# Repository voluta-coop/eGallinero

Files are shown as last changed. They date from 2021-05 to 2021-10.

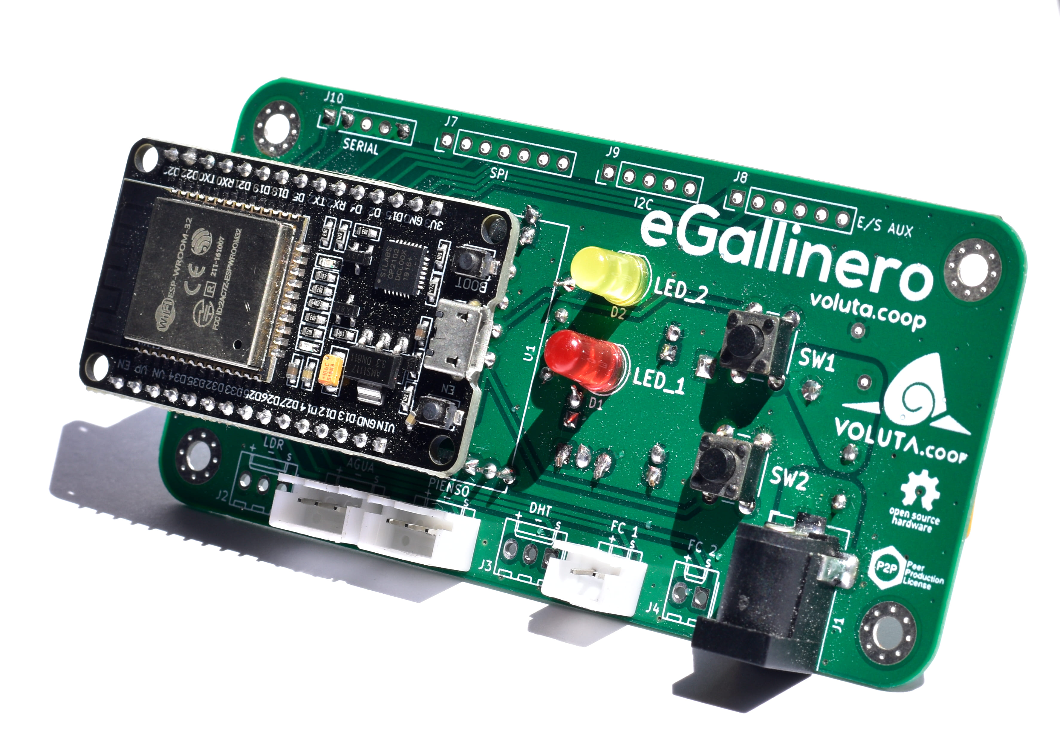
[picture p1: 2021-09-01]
Images/_DSC0914.jpg

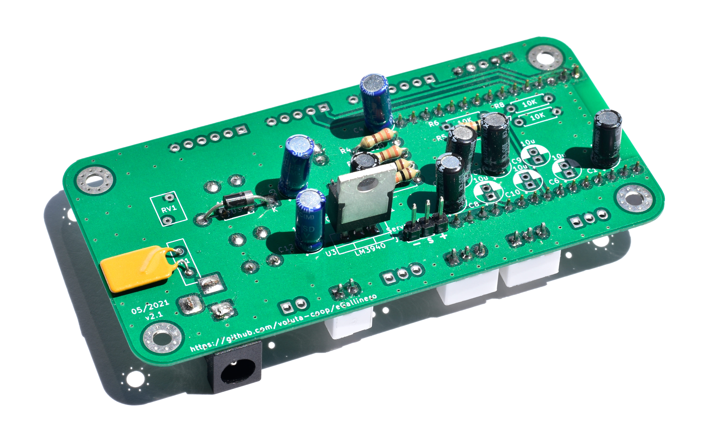
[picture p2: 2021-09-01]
Images/_DSC0912.jpg

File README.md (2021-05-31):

# eGallinero
El eGallinero es un sistema modular, diseñado para facilitar las tareas que conllevan los cuidados a los animales. En nuestro caso lo hemos enfocado comercialmente a las gallinas para alinearlo con nuestro objeto social, conectar mundo rural y urbano... pero se puede utilizar para multitud de aplicaciones que requieran automatización y monitorización.

¡Reserva el tuyo!

[**RESERVA**](https://www.voluta.coop/taller-iot-competencias-digitales/)  

[**Canal de Telegram**](https://t.me/eGallinero)

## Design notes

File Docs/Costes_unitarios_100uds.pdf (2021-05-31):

Concepto | €
Componentes + embalaje + transporte | 24,82 €
Mano de obra + gestión del pedido + postventa | 24,49 €
Beneficio empresarial | 7,72 €
IVA (21%) | 11,98 €
TOTAL | 69,00 €

A continuación desglosamos el precio de cada Kit eGallinero asumiendo una fabricación en lotes de 100 unidades:

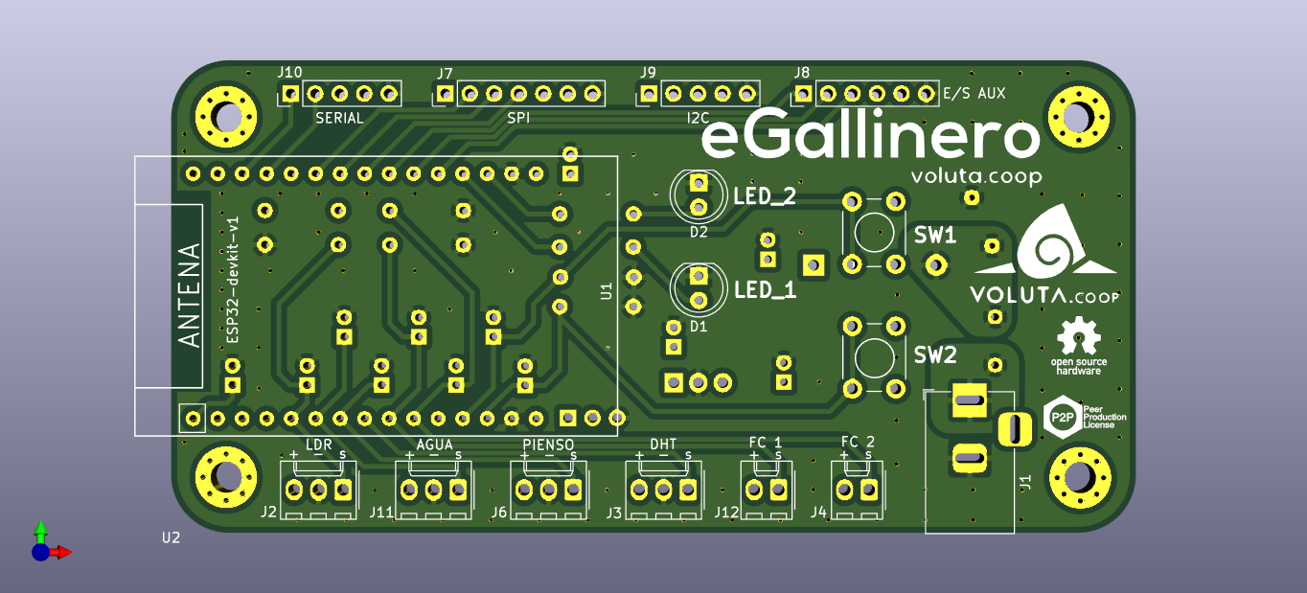
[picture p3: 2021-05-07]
Images/eGallinero_TOP.png

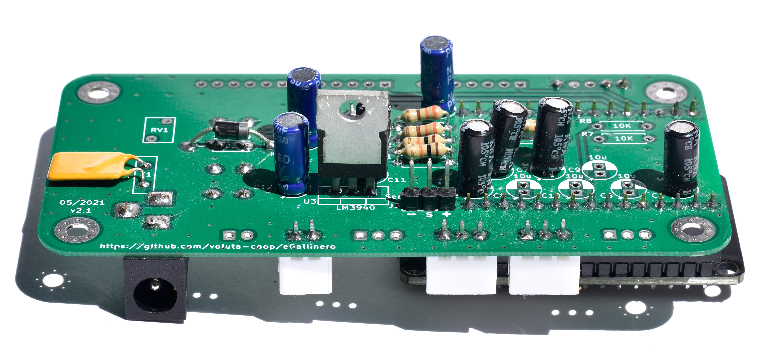
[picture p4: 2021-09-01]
Images/_DSC0917.jpg

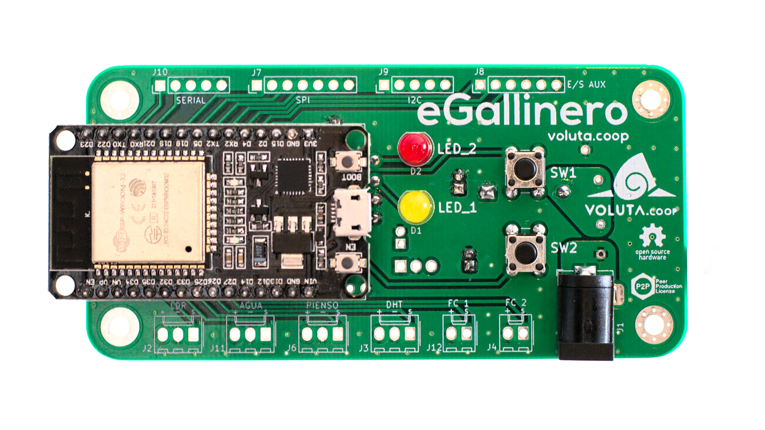
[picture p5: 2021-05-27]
Images/eGallinero.jpg

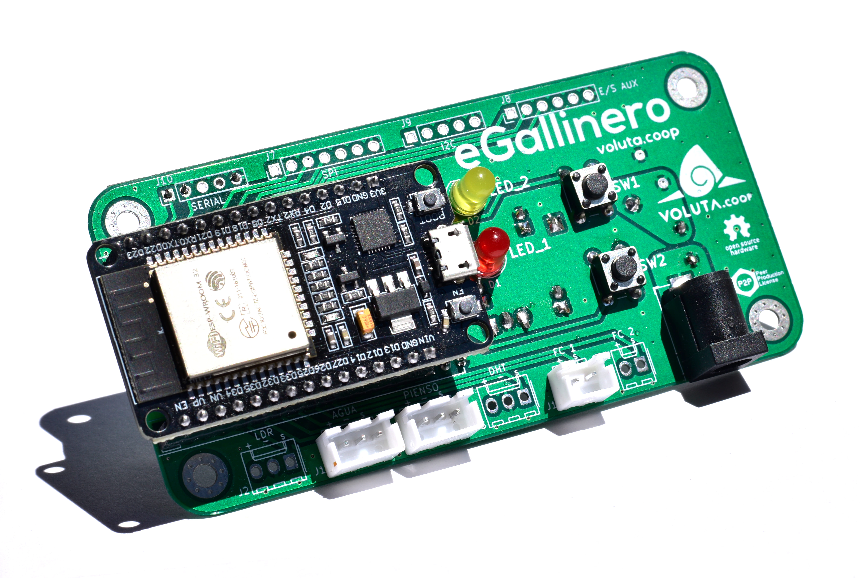
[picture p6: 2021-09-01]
Images/_DSC0913.jpg

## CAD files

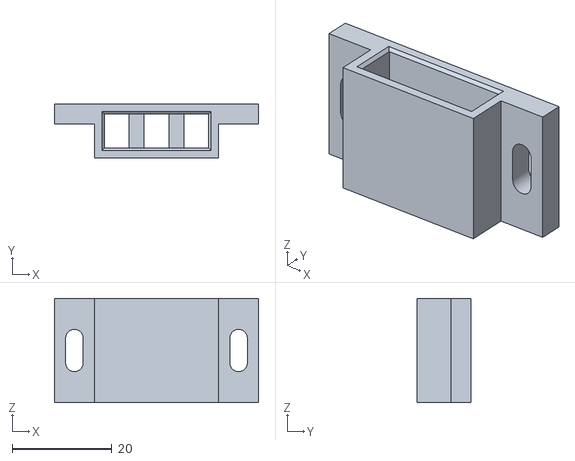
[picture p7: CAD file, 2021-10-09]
HW/3D/soporte_final_de_carrera.stl
41.0 x 10.8 x 21.0

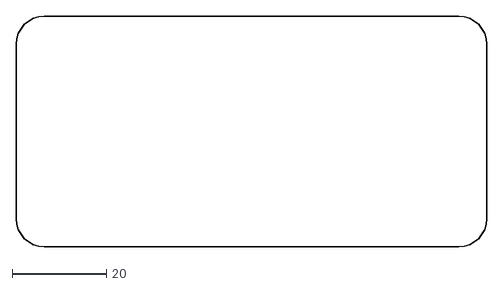
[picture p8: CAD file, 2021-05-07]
HW/kicad/eGallinero/edge.dxf
100.0 x 49.0

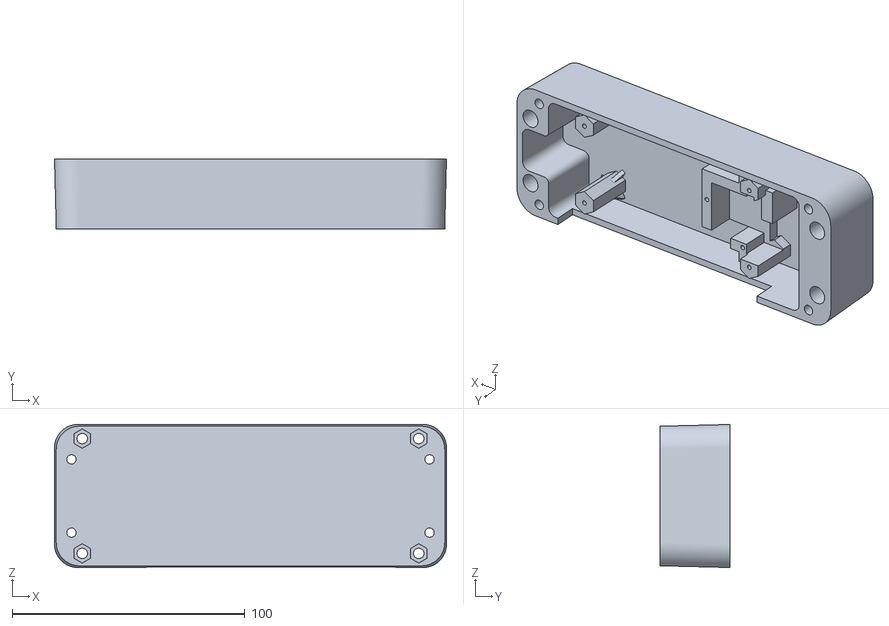
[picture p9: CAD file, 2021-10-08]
HW/3D/caja.stl
168.5 x 30.0 x 61.5

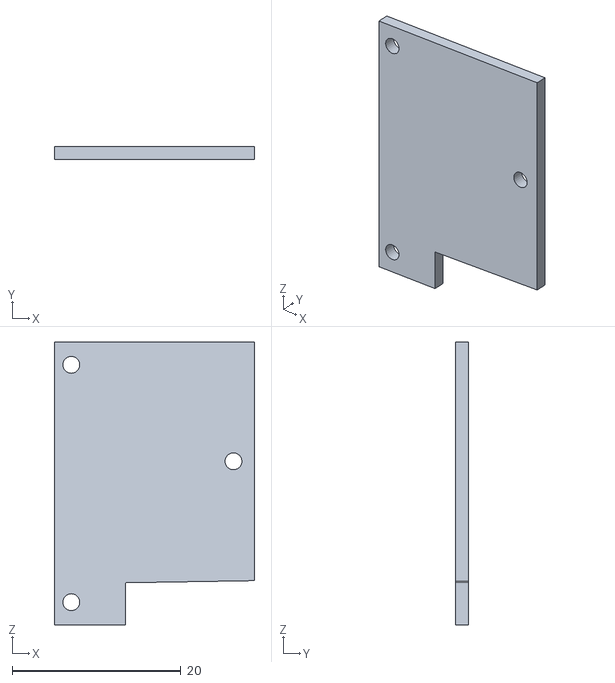
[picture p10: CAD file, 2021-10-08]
HW/3D/tapa_ servo.stl
23.7 x 1.50 x 33.5

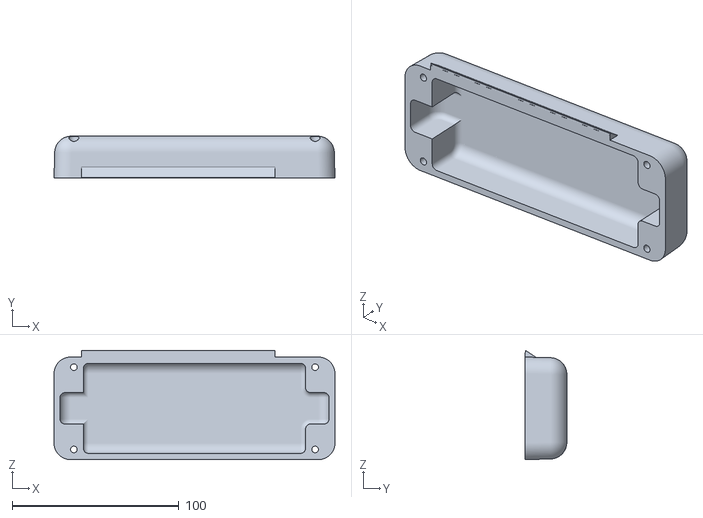
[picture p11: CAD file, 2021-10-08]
HW/3D/tapa_ caja.stl
168.5 x 25.0 x 65.5

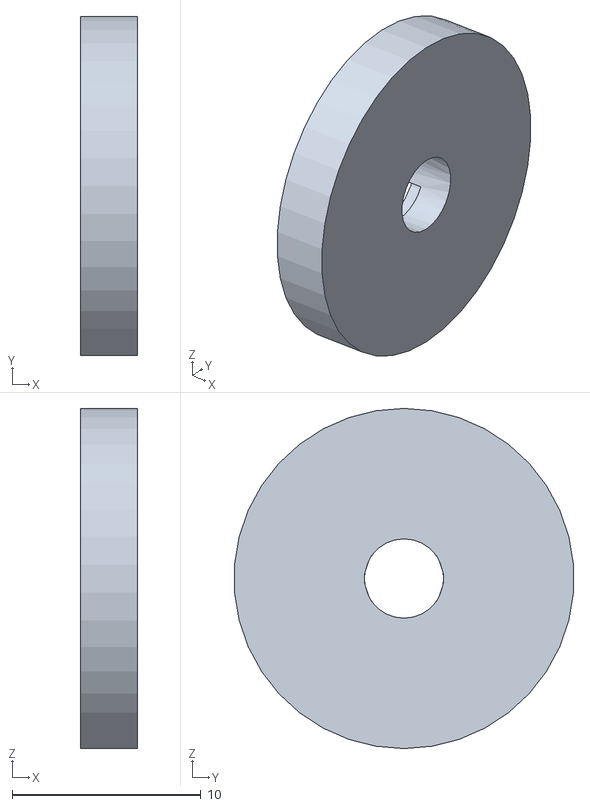
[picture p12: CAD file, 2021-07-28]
HW/3D/Bobina_1.stl
3.00 x 17.9 x 18.0

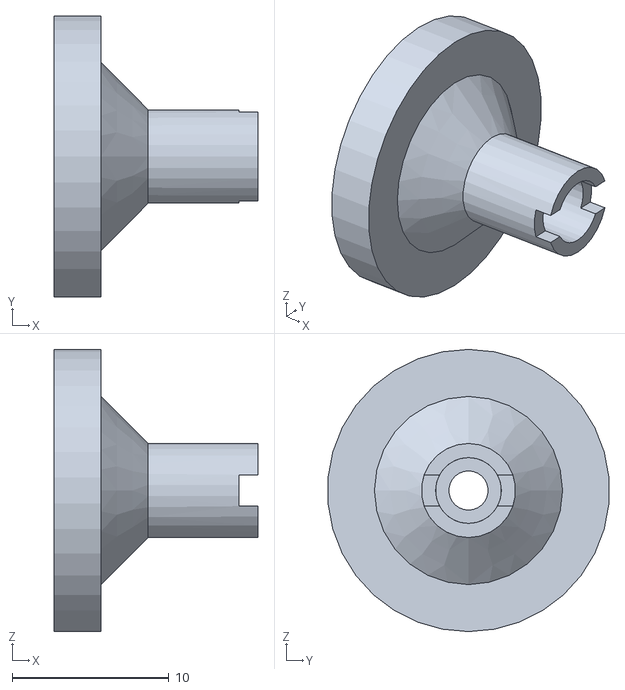
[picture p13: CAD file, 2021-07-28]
HW/3D/Bobina_2.stl
13.0 x 17.9 x 18.0

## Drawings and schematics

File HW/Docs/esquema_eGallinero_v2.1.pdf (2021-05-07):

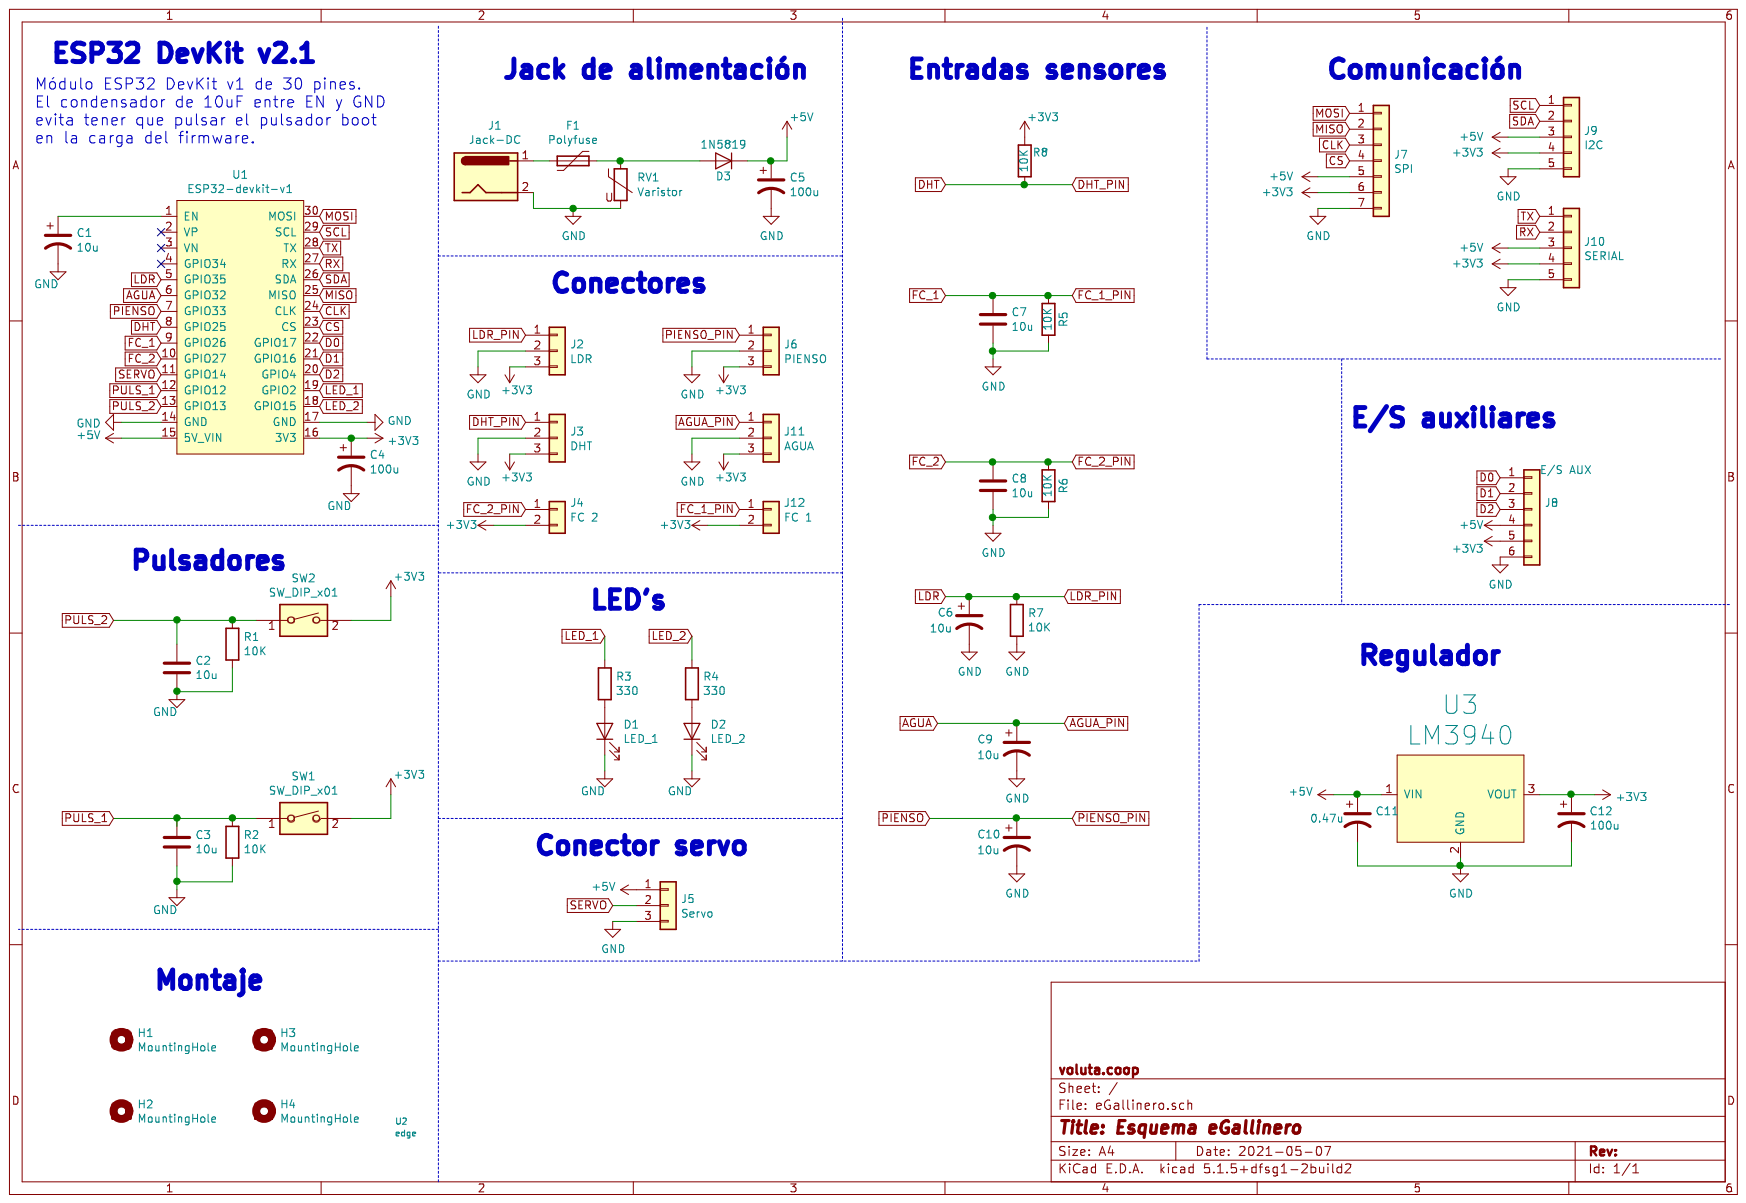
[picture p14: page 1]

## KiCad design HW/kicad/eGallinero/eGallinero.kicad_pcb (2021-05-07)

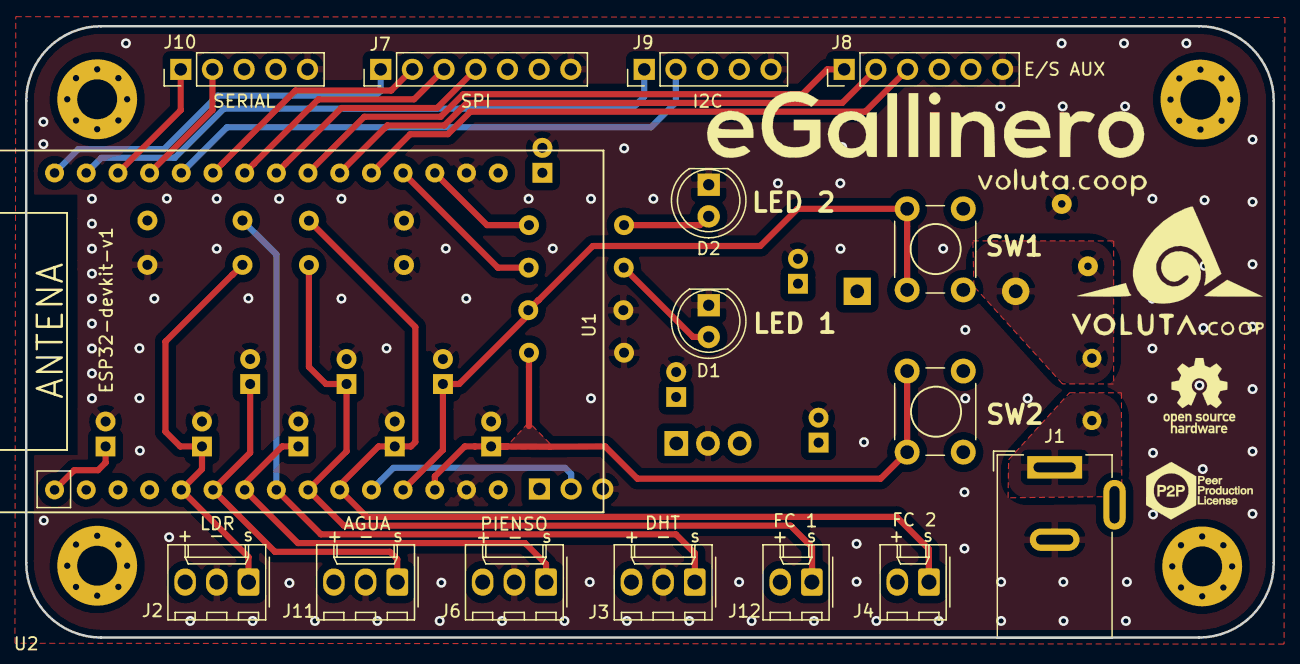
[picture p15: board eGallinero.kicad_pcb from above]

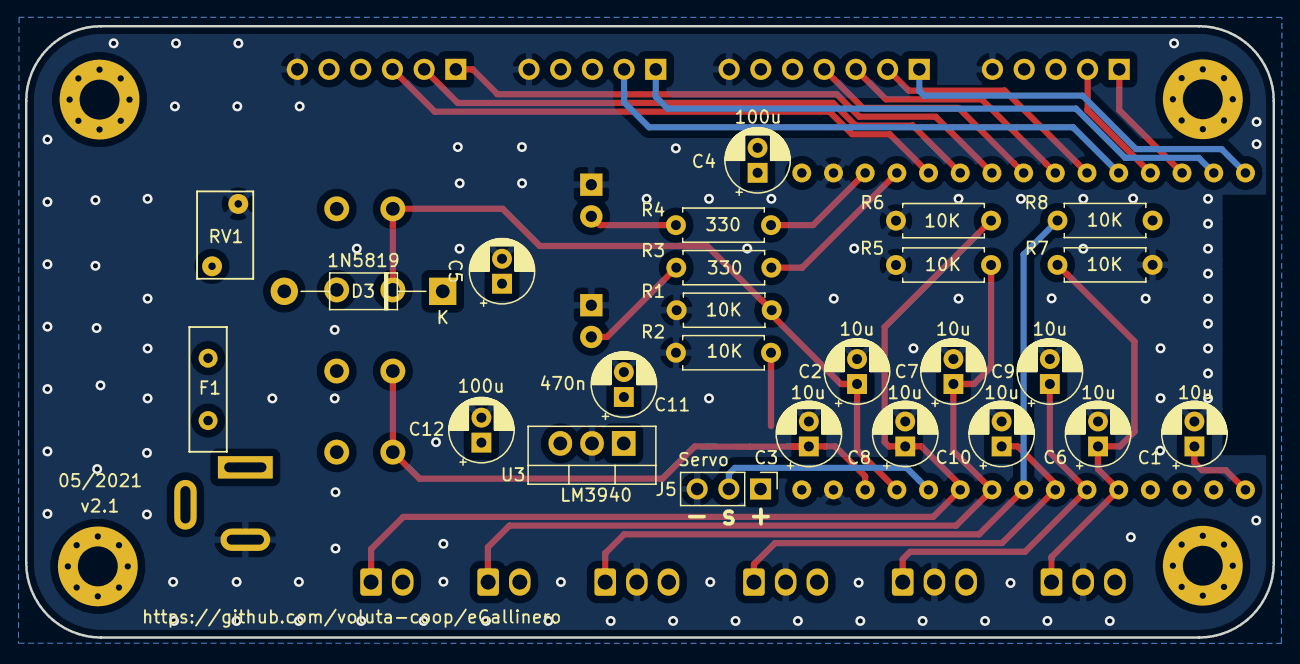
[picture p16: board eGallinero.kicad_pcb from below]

Board: 4 copper layers, 100.0 x 49.0 mm, 46 parts (25 on the bottom side), 30 nets.

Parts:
C1, C2, C3, C6, C7, C8, C9, C10: 10u; CP_Radial_D5.0mm_P2.00mm
C4, C5, C12: 100u; CP_Radial_D5.0mm_P2.00mm
C11: 470n; CP_Radial_D5.0mm_P2.00mm
D1: LED 1; LED_D5.0mm_Clear
D2: LED 2; LED_D5.0mm_Clear
D3: 1N5819; D_DO-41_SOD81_P12.70mm_Horizontal
F1: Polyfuse; AHEF100
H1, H2, H3, H4: MountingHole; MountingHole_3.2mm_M3_Pad_Via
J1: Jack-DC; BarrelJack_Wuerth_6941xx301002
J2: LDR; Molex_KK-254_AE-6410-03A_1x03_P2.54mm_Vertical
J3: DHT; Molex_KK-254_AE-6410-03A_1x03_P2.54mm_Vertical
J4: FC 2; Molex_KK-254_AE-6410-02A_1x02_P2.54mm_Vertical
J5: Servo; PinHeader_1x03_P2.54mm_Vertical
J6: PIENSO; Molex_KK-254_AE-6410-03A_1x03_P2.54mm_Vertical
J7: SPI; PinHeader_1x07_P2.54mm_Vertical
J8: E/S AUX; PinHeader_1x06_P2.54mm_Vertical
J9: I2C; PinHeader_1x05_P2.54mm_Vertical
J10: SERIAL; PinHeader_1x05_P2.54mm_Vertical
J11: AGUA; Molex_KK-254_AE-6410-03A_1x03_P2.54mm_Vertical
J12: FC 1; Molex_KK-254_AE-6410-02A_1x02_P2.54mm_Vertical
R1, R2, R5, R6, R7, R8: 10K; R_Axial_DIN0207_L6.3mm_D2.5mm_P7.62mm_Horizontal
R3, R4: 330; R_Axial_DIN0207_L6.3mm_D2.5mm_P7.62mm_Horizontal
RV1: Varistor; RV_Disc_D7mm_W4.5mm_P5mm
SW1, SW2: SW_DIP_x01; SW_PUSH_6mm_H4.3mm
U1: ESP32-devkit-v1; ESP32-DevKit-v1
U2: edge
U3: LM3940; TO-220-3_Vertical

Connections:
+3V3: C4.1, C12.1, J2.3, J3.3, J4.2, J6.3, J7.6, J8.5, J9.4, J10.4, J11.3, J12.2, R8.2, SW1.2, SW2.2, U1.16, U3.3
+5V: C5.1, C11.1, D3.1, J5.1, J7.5, J8.4, J9.3, J10.3, U1.15, U3.1
AGUA: C9.1, J11.1, U1.6
CLK: J7.3, U1.24
CS: J7.4, U1.23
D0: J8.1, U1.22
D1: J8.2, U1.21
D2: J8.3, U1.20
DHT: J3.1, R8.1, U1.8
FC_1: C7.1, J12.1, R5.2, U1.9
FC_2: C8.1, J4.1, R6.2, U1.10
GND: C1.2, C2.2, C3.2, C4.2, C5.2, C6.2, C7.2, C8.2, C9.2, C10.2, C11.2, C12.2, D1.1, D2.1, J1.2, J2.2, J3.2, J5.3, J6.2, J7.7, J8.6, J9.5, J10.5, J11.2, R1.2, R2.2, R5.1, R6.1, R7.2, RV1.2, U1.14, U1.17, U3.2
LDR: C6.1, J2.1, R7.1, U1.5
LED_1: R3.1, U1.19
LED_2: R4.1, U1.18
MISO: J7.2, U1.25
MOSI: J7.1, U1.30
unnamed: C1.1, U1.1
unnamed: D1.2, R3.2
unnamed: D2.2, R4.2
unnamed: D3.2, F1.1, RV1.1
unnamed: F1.2, J1.1
PIENSO: C10.1, J6.1, U1.7
PULS_1: C2.1, R1.1, SW1.1, U1.12
PULS_2: C3.1, R2.1, SW2.1, U1.13
RX: J10.2, U1.27
SCL: J9.1, U1.29
SDA: J9.2, U1.26
SERVO: J5.2, U1.11
TX: J10.1, U1.28

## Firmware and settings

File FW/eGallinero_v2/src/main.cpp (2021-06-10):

#include <Arduino.h>
#include <WiFi.h>
#include <WiFiClientSecure.h>
#include <ArduinoJson.h>
#include <NewPing.h>
#include <TimeLib.h>
#include <ESP32Servo.h>
#include <UniversalTelegramBot.h>


/************** CONFIGURACIÓN **************/

#define WIFI_AP_NAME "XXXXXXXXXXXXXXXx"
#define WIFI_PASSWORD "XXXXXXXXXXXXXX"
#define DIST_MAX_AGUA 50
#define DIST_MIN_AGUA 6
#define DIST_MAX_PIENSO 50
#define DIST_MIN_PIENSO 6
#define BOT_TOKEN "XXXXXXXXX:XXXXXXXXXXXXXXXXXXXXXXXXXXXXXXX"
#define CHAT_ID "XXXXXXXXXX"
#define NIVEL_ALERTA_PIENSO 20
#define NIVEL_ALERTA_AGUA 20

/*·············· HORARIOS ···················*/                   
#define HORA_APERTURA_ENERO         8
#define MINUTO_APERTURA_ENERO       30
#define HORA_CIERRE_ENERO           19
#define MINUTO_CIERRE_ENERO         00

#define HORA_APERTURA_FEBRERO       8
#define MINUTO_APERTURA_FEBRERO     30
#define HORA_CIERRE_FEBRERO         19
#define MINUTO_CIERRE_FEBRERO       30

#define HORA_APERTURA_MARZO         8
#define MINUTO_APERTURA_MARZO       30
#define HORA_CIERRE_MARZO           20
#define MINUTO_CIERRE_MARZO         00

#define HORA_APERTURA_ABRIL         8
#define MINUTO_APERTURA_ABRIL       30
#define HORA_CIERRE_ABRIL           21
#define MINUTO_CIERRE_ABRIL         30

#define HORA_APERTURA_MAYO          8
#define MINUTO_APERTURA_MAYO        30
#define HORA_CIERRE_MAYO            22
#define MINUTO_CIERRE_MAYO          00

#define HORA_APERTURA_JUNIO         8
#define MINUTO_APERTURA_JUNIO       30
#define HORA_CIERRE_JUNIO           22
#define MINUTO_CIERRE_JUNIO         0

#define HORA_APERTURA_JULIO         8
#define MINUTO_APERTURA_JULIO       30
#define HORA_CIERRE_JULIO           22
#define MINUTO_CIERRE_JULIO         15

#define HORA_APERTURA_AGOSTO        8
#define MINUTO_APERTURA_AGOSTO      30
#define HORA_CIERRE_AGOSTO          22
#define MINUTO_CIERRE_AGOSTO        00

#define HORA_APERTURA_SEPTIEMPBRE   8
#define MINUTO_APERTURA_SEPTIEMPBRE 30
#define HORA_CIERRE_SEPTIEMPBRE     21
#define MINUTO_CIERRE_SEPTIEMPBRE   45

#define HORA_APERTURA_OCTUBRE       8
#define MINUTO_APERTURA_OCTUBRE     30
#define HORA_CIERRE_OCTUBRE         20
#define MINUTO_CIERRE_OCTUBRE       30

#define HORA_APERTURA_NOVIEMBRE     8
#define MINUTO_APERTURA_NOVIEMBRE   30
#define HORA_CIERRE_NOVIEMBRE       18
#define MINUTO_CIERRE_NOVIEMBRE     40

#define HORA_APERTURA_DICIEMBRE     8
#define MINUTO_APERTURA_DICIEMBRE   30
#define HORA_CIERRE_DICIEMBRE       18
#define MINUTO_CIERRE_DICIEMBRE     30

/****************** FIN DE LA CONFIGURACIÓN ******************/


// Pines
#define PIN_LED_1 2
#define PIN_LED_2 15
#define PIN_PULSADOR_1 12
#define PIN_PULSADOR_2 13
#define PIN_AGUA 32
#define PIN_PIENSO 33
#define PIN_SERVO 14

// Lectura sensores
#define N_LEC 20 // Número de lecturas para hacer la media de los niveles

// Mensajes Telegram
#define MENSAJE_DIARIO ""
#define MENSAJE_PIENSO "Queda poco pienso."
#define MENSAJE_AGUA "Queda poca agua."

//Estados de configuración

#define CONFIG_DOOR_DOWN 0
#define CONFIG_DOOR_UP 1
#define CONFIG_DOOR_TEST_DOWN 2
#define CONFIG_DOOR_TEST_UP 3
#define CONFIG_DOOR_OK 4

// Estados de funcionamiento
#define OPERATION_WIFI 5
#define OPERATION_HORA 6
#define OPERATION_TELEGRAM 7
#define OPERATION_PUERTA 8
#define OPERATION_SENSORES 9

//Constantes Servo
#define PARO 90
#define SUBIR 0
#define BAJAR 180

// Constantes LEDs
#define OFF 1000
#define ON 100
#define F_1HZ 1
#define F_2HZ 2
#define F_5HZ 5
#define F_10HZ 10

// Conversiones
#define MIN_TO_MS 60000

// Telegram
const unsigned long BOT_MTBS = 1000; // mean time between scan messages

WiFiClientSecure secured_client;
UniversalTelegramBot bot(BOT_TOKEN, secured_client);

unsigned long bot_lasttime; // last time messages' scan has been done

int state = 0;
int contador_pienso = 0;
int contador_agua = 0;

bool puerta_telegram = false;
bool aviso_error_config_puerta = false;


// Variables puerta
int servo = PARO;
bool abrir = false;
bool cerrar = false;
bool abierto = false;
bool cerrado = false;

// Variables de los LEDs
bool state_led_1 = LOW;
bool state_led_2 = LOW;
bool state_led_1_last = LOW;
bool state_led_2_last = LOW;

//Variables pulsadores
bool state_p_1 = false;
bool state_p_2 = false;
bool state_p_1_last = false;
bool state_p_2_last = false;

// Variables de tiempo generales
unsigned long  previousMillis_1 = 0;
unsigned long  previousMillis_2 = 0;
unsigned long  t_p_1 = 0;
unsigned long  t_p_2 = 0;
unsigned long  t_servo = 0;
unsigned long  t_servo_crono = 0;

// Variables sensores
int nivel_agua = 0;
int nivel_pienso = 0;


NewPing agua(PIN_AGUA, PIN_AGUA, DIST_MAX_AGUA);
NewPing pienso(PIN_PIENSO, PIN_PIENSO, DIST_MAX_PIENSO);

//Servo
Servo puerta;

// Tiempo
static const char ntpServerName[] = "3.es.pool.ntp.org";
const int timeZone = 1;     // Central European Time

WiFiUDP Udp;
unsigned int localPort = 8888;  // local port to listen for UDP packets
const int NTP_PACKET_SIZE = 48; // NTP time is in the first 48 bytes of message
byte packetBuffer[NTP_PACKET_SIZE]; //buffer to hold incoming & outgoing packets

void sendNTPpacket(IPAddress &address)
{
  // set all bytes in the buffer to 0
  memset(packetBuffer, 0, NTP_PACKET_SIZE);
  // Initialize values needed to form NTP request
  // (see URL above for details on the packets)
  packetBuffer[0] = 0b11100011;   // LI, Version, Mode
  packetBuffer[1] = 0;     // Stratum, or type of clock
  packetBuffer[2] = 6;     // Polling Interval
  packetBuffer[3] = 0xEC;  // Peer Clock Precision
  // 8 bytes of zero for Root Delay & Root Dispersion
  packetBuffer[12] = 49;
  packetBuffer[13] = 0x4E;
  packetBuffer[14] = 49;
  packetBuffer[15] = 52;
  // all NTP fields have been given values, now
  // you can send a packet requesting a timestamp:
  Udp.beginPacket(address, 123); //NTP requests are to port 123
  Udp.write(packetBuffer, NTP_PACKET_SIZE);
  Udp.endPacket();
}

time_t getNtpTime()
{
  IPAddress ntpServerIP; // NTP server's ip address

  while (Udp.parsePacket() > 0) ; // discard any previously received packets
  Serial.println("Transmit NTP Request");
  // get a random server from the pool
  WiFi.hostByName(ntpServerName, ntpServerIP);
  Serial.print(ntpServerName);
  Serial.print(": ");
  Serial.println(ntpServerIP);
  sendNTPpacket(ntpServerIP);
  uint32_t beginWait = millis();
  while (millis() - beginWait < 1500) {
    int size = Udp.parsePacket();
    if (size >= NTP_PACKET_SIZE) {
      Serial.println("Receive NTP Response");
      Udp.read(packetBuffer, NTP_PACKET_SIZE);  // read packet into the buffer
      unsigned long secsSince1900;
      // convert four bytes starting at location 40 to a long integer
      secsSince1900 =  (unsigned long)packetBuffer[40] << 24;
      secsSince1900 |= (unsigned long)packetBuffer[41] << 16;
      secsSince1900 |= (unsigned long)packetBuffer[42] << 8;
      secsSince1900 |= (unsigned long)packetBuffer[43];
      return secsSince1900 - 2208988800UL + timeZone * SECS_PER_HOUR;
    }
  }
  Serial.println("No NTP Response :-(");
  return 0; // return 0 if unable to get the time
}

void handleNewMessages(int numNewMessages)
{
  for (int i = 0; i < numNewMessages; i++)
  {
    String text = bot.messages[i].text;
    
    if(text == "Abrir" || text == "abrir") {

        if(abierto == true) bot.sendMessage(CHAT_ID, "La puerta ya está abierta.", "");
        else{
            cerrar = false;
            abrir = true;
        }
    }
    else if (text = "Cerrar" || text == "cerrar") {

        if(cerrado == true) bot.sendMessage(CHAT_ID, "La puerta ya está cerrada.", "");
        else{
            cerrar = true;
            abrir = false;
        }
    }

    if(abrir || cerrar) puerta_telegram = true;
  }
}


void outputs(){

    digitalWrite(PIN_LED_1, state_led_1);
    digitalWrite(PIN_LED_2, state_led_2);
    if(state != OPERATION_HORA && state != OPERATION_WIFI) puerta.write(servo);

}

void leds(int freq_1, int freq_2){ // Esta función enciende el led que se indica y a la frecuencia que se le indica en Hz
    
    int per_1 = 500/freq_1;
    int per_2 = 500/freq_2;

    
    if((millis() - previousMillis_1) >= per_1 && freq_1 != OFF && freq_1 != ON){
        state_led_1 = !state_led_1;
        previousMillis_1 = millis();
    }
    else if(freq_1 == OFF) state_led_1 = LOW;
    else if(freq_1 == ON) state_led_1 = HIGH;

    if((millis() - previousMillis_2) >= per_2 && freq_2 != OFF && freq_2 != ON){
        state_led_2 = !state_led_2;
        previousMillis_2 = millis();
    }
    else if(freq_2 == OFF) state_led_2 = LOW;
    else if(freq_2 == ON) state_led_2 = HIGH;
}

void niveles(){
    
    bool niveles_ok = false;

    while(niveles_ok == false){

        int lec_agua = 0;
        int lec_pienso = 0;
        int media_agua = 0;
        int media_pienso = 0;
        

        for(int i = 0; i < N_LEC; i++){
            lec_agua += agua.ping_cm();
            delay(80);
        }
        delay(3000);
        for(int i = 0; i < N_LEC; i++){   
            lec_pienso += pienso.ping_cm();
            delay(80);
        }

        media_agua = lec_agua/N_LEC;
        media_pienso = lec_pienso/N_LEC;

        nivel_agua = map(media_agua,DIST_MIN_AGUA,DIST_MAX_AGUA,100,0);
        nivel_pienso = map(media_pienso,DIST_MIN_PIENSO,DIST_MAX_PIENSO,100,0);

        Serial.println(nivel_agua);
        Serial.println(nivel_pienso);

        if((media_pienso =! 0) && (media_agua != 0)) niveles_ok = true;
        else niveles_ok = false;
    }
}

void inputs(){
    
    state_p_1_last = state_p_1;
    state_p_2_last = state_p_2;
    state_p_1 = digitalRead(PIN_PULSADOR_1);
    state_p_2 = digitalRead(PIN_PULSADOR_2);
}

void sensores(){
    niveles();
}

void telegram(){

    previousMillis_2 = millis();

        while (millis() - previousMillis_2 < 1 * MIN_TO_MS){
            
            if (millis() - bot_lasttime > BOT_MTBS){
                int numNewMessages = bot.getUpdates(bot.last_message_received + 1);
            
                while (numNewMessages){
                    Serial.println("got response");
                    handleNewMessages(numNewMessages);
                    numNewMessages = bot.getUpdates(bot.last_message_received + 1);
                }

                bot_lasttime = millis();
            }

            if(puerta_telegram == true){
            state = OPERATION_PUERTA;
        }

            if(abrir == true || cerrar == true) break;
        }

        if(puerta_telegram == true){
            state = OPERATION_PUERTA;
        }
    

    if(abrir == true && puerta_telegram == false) bot.sendMessage(CHAT_ID, MENSAJE_DIARIO, "");
    else if(abrir == true && puerta_telegram == true) bot.sendMessage(CHAT_ID, "Abriendo...", "");
    else if(cerrar == true && puerta_telegram == true) bot.sendMessage(CHAT_ID, "Cerrando...", "");

    if(nivel_pienso <= NIVEL_ALERTA_PIENSO) contador_pienso++; 
    if(nivel_agua <= NIVEL_ALERTA_AGUA) contador_agua++;

    if(t_servo == 0 && aviso_error_config_puerta == false) {
        aviso_error_config_puerta = true;
        bot.sendMessage(CHAT_ID, "La puerta no está configurada, consulta el manual de configuración: https://github.com/voluta-coop/eGallinero", "");
    }
    
    if(contador_pienso >= 30) bot.sendMessage(CHAT_ID, MENSAJE_PIENSO, "");
    
    if(contador_agua >= 30) bot.sendMessage(CHAT_ID, MENSAJE_AGUA, "");
    
    if(contador_agua >= 30) contador_agua = 0;
    if(contador_pienso >= 30) contador_pienso = 0;

    Serial.print("contador agua: ");
    Serial.println(contador_agua);
}

void setup(){
    
    Serial.begin(9600);

    pinMode(PIN_LED_1, OUTPUT);
    pinMode(PIN_LED_2, OUTPUT);
    pinMode(PIN_PULSADOR_1, INPUT);
    pinMode(PIN_PULSADOR_2, INPUT);

    //Config Servo

    // Allow allocation of all timers
	ESP32PWM::allocateTimer(0);
	ESP32PWM::allocateTimer(1);
	ESP32PWM::allocateTimer(2);
	ESP32PWM::allocateTimer(3);
	puerta.setPeriodHertz(50);    // standard 50 hz servo
    
	puerta.attach(PIN_SERVO, 500, 2400);

    outputs();
}

void loop() {
    switch(state){
        
        case CONFIG_DOOR_DOWN:

            Serial.println("DOWN");

            while(state == CONFIG_DOOR_DOWN){

                inputs();

                if((state_p_2 && state_p_2_last)){
                    leds(ON, F_5HZ);
                     servo = BAJAR;
                }

                else{
                    leds(OFF, F_5HZ);
                     servo = PARO;
                }

                if(state_p_1 && !state_p_1_last) state = CONFIG_DOOR_UP;

                outputs();
            }
        break;

        case CONFIG_DOOR_UP:
            while(state == CONFIG_DOOR_UP){
                inputs();
                Serial.println("UP");

                if((state_p_2 && state_p_2_last)){
                    leds(F_5HZ,ON);
                     servo = SUBIR;
                }
                else{
                    leds(F_5HZ, OFF);
                     servo = PARO;
                }

                if(state_p_2 && !state_p_2_last) t_p_2 = millis();
                if((!state_p_2 && state_p_2_last)) t_servo += millis() - t_p_2;

                if(state_p_1 && !state_p_1_last) state = CONFIG_DOOR_TEST_DOWN;
                
                outputs();
            }
        break;

        case CONFIG_DOOR_TEST_DOWN:

            Serial.println("Test Down");

            Serial.println(t_servo);
            Serial.println(t_servo/1.3);

            t_servo_crono = millis();

            while(state == CONFIG_DOOR_TEST_DOWN){
                
                inputs();

                if(millis() - t_servo_crono < t_servo / 1.3){
                    leds(OFF, F_2HZ);
                    servo = BAJAR;
                    }
                else {
                    servo = PARO;
                    leds(OFF, ON);
                    if(state_p_1 && !state_p_1_last) state = CONFIG_DOOR_TEST_UP;
                    if(state_p_2 && !state_p_2_last) state = CONFIG_DOOR_DOWN;  
                }

                outputs();
            }
        break;

        case CONFIG_DOOR_TEST_UP:

            Serial.println("Test Up");

            t_servo_crono = millis();

            while(state == CONFIG_DOOR_TEST_UP){

                inputs();

                if(millis() - t_servo_crono < t_servo){
                    leds(F_2HZ, OFF);
                    servo = SUBIR;
                    }
                else {
                    servo = PARO;
                    leds(ON, OFF);
                    abierto = true;
                    if(state_p_1 && !state_p_1_last) state = CONFIG_DOOR_OK;
                }

                outputs();
            }
        break;

        case CONFIG_DOOR_OK:

            Serial.println("Ok?");
            delay(500);

            while(state == CONFIG_DOOR_OK){

                inputs();
                
                leds(F_1HZ, F_1HZ);         

                if(state_p_1 && !state_p_1_last) state = OPERATION_WIFI;
                else if(state_p_2 && !state_p_2_last) state = CONFIG_DOOR_TEST_DOWN;

                outputs();
            }
        break;

        case OPERATION_WIFI:

            Serial.println("WiFi");

            leds(OFF, OFF);
            outputs();

            WiFi.begin(WIFI_AP_NAME, WIFI_PASSWORD);

            secured_client.setCACert(TELEGRAM_CERTIFICATE_ROOT); // Add root certificate for api.telegram.org
            
            while (WiFi.status() != WL_CONNECTED){
                delay(100);
            }

            if(WiFi.status() == WL_CONNECTED) state = OPERATION_HORA;
            
        break;

        case OPERATION_HORA:

            Serial.println("Hora");

            Udp.begin(localPort);
            setSyncProvider(getNtpTime);
            setSyncInterval(300);

            while(state == OPERATION_HORA && WiFi.status() == WL_CONNECTED){

                int horario_apertura[12][2] = 
                {{HORA_APERTURA_ENERO, MINUTO_APERTURA_ENERO},
                {HORA_APERTURA_FEBRERO, MINUTO_APERTURA_FEBRERO},
                {HORA_APERTURA_MARZO, MINUTO_APERTURA_MARZO},
                {HORA_APERTURA_ABRIL, MINUTO_APERTURA_ABRIL},
                {HORA_APERTURA_MAYO, MINUTO_APERTURA_MAYO},
                {HORA_APERTURA_JUNIO, MINUTO_APERTURA_JUNIO},
                {HORA_APERTURA_JULIO, MINUTO_APERTURA_JULIO},
                {HORA_APERTURA_AGOSTO, MINUTO_APERTURA_AGOSTO},
                {HORA_APERTURA_SEPTIEMPBRE, MINUTO_APERTURA_SEPTIEMPBRE},
                {HORA_APERTURA_OCTUBRE, MINUTO_APERTURA_OCTUBRE},
                {HORA_APERTURA_NOVIEMBRE, MINUTO_APERTURA_NOVIEMBRE},
                {HORA_APERTURA_DICIEMBRE, MINUTO_APERTURA_DICIEMBRE}};

                int horario_cierre[12][2] = {{HORA_CIERRE_ENERO, MINUTO_CIERRE_ENERO},
                {HORA_CIERRE_FEBRERO, MINUTO_CIERRE_FEBRERO},
                {HORA_CIERRE_MARZO, MINUTO_CIERRE_MARZO},
                {HORA_CIERRE_ABRIL, MINUTO_CIERRE_ABRIL},
                {HORA_CIERRE_MAYO, MINUTO_CIERRE_MAYO},
                {HORA_CIERRE_JUNIO, MINUTO_CIERRE_JUNIO},
                {HORA_CIERRE_JULIO, MINUTO_CIERRE_JULIO},
                {HORA_CIERRE_AGOSTO, MINUTO_CIERRE_AGOSTO},
                {HORA_CIERRE_SEPTIEMPBRE, MINUTO_CIERRE_SEPTIEMPBRE},
                {HORA_CIERRE_OCTUBRE, MINUTO_CIERRE_OCTUBRE},
                {HORA_CIERRE_NOVIEMBRE, MINUTO_CIERRE_NOVIEMBRE},
                {HORA_CIERRE_DICIEMBRE, MINUTO_CIERRE_DICIEMBRE}};

                int hora = hour() + 1;
                if (hora >= 24) hora = 0;

                int minuto = minute();
                int dia = day();
                int mes = month();
                int minuto_diario = hora * 60 + minuto;
                int minuto_apertura = horario_apertura[mes-1][0] * 60 + horario_apertura[mes-1][1];
                int minuto_cierre = horario_cierre[mes-1][0] * 60 + horario_cierre[mes-1][1];
                inputs();
                
                Serial.println(dia);
                Serial.println(mes);
                Serial.println(minuto_diario);
                Serial.println(minuto_apertura);
                Serial.println(minuto_cierre);

                if(cerrado == true && ( minuto_diario >= minuto_apertura && minuto_diario < minuto_cierre)) {
                    abrir   = true;
                    cerrar  = false;
                    Serial.println("Es hora de abrir.");
                }
                else if(abierto == true && ( minuto_diario < minuto_apertura || minuto_diario >= minuto_cierre)){
                     cerrar = true;
                     abrir  = false;
                    Serial.println("Es hora de cerrar.");
                }
                else{
                    abrir   = false;
                    cerrar  = false;
                    if(abierto == true) Serial.println("Ya está abierto");
                    else if(cerrado == true) Serial.println("Ya está cerrado");
                }
                
                outputs();

                if(WiFi.status() != WL_CONNECTED) state = OPERATION_WIFI;
                else if((hora != 0 && minuto != 0 && dia != 0 && mes != 0) && (abrir == true || cerrar == true) ) {
                    state = OPERATION_PUERTA;
                    Serial.println("Hora: ");
                    Serial.print(hora);Serial.print(":");Serial.println(minuto);
                }

                else {
                    Serial.println("Hora: ");
                    Serial.print(hora);Serial.print(":");Serial.println(minuto);
                    state = OPERATION_SENSORES;}

                if(hora * 60 + minuto <= 30) puerta_telegram = false;
            }

        
        
        if(abierto == true) abrir = false;
        if(cerrado == true) cerrar = false;

        break;

        case OPERATION_SENSORES:

        Serial.println("Sensores");

        sensores();

        state = OPERATION_TELEGRAM;

        break;

        case OPERATION_TELEGRAM:

        Serial.println("Telegram");

            telegram();

        state = OPERATION_HORA;

        break;

        case OPERATION_PUERTA:

            Serial.println("Puerta");
            Serial.print("abrir ");Serial.println(abrir);
            Serial.print("cerrar: ");Serial.println(cerrar);
            Serial.print("abierto: ");Serial.println(abierto);
            Serial.print("cerrado: ");Serial.println(cerrado);
            Serial.print("puerta_telegram: ");Serial.println(puerta_telegram);

            bool var_aux_abrir = false;
            bool var_aux_cerrar = false; 

            while(state == OPERATION_PUERTA){
                
                if(abrir == true && cerrado == true){
                    
                    if(var_aux_abrir == false) {
                        t_servo_crono = millis();
                        var_aux_abrir = true;
                    }


                    if(millis() - t_servo_crono < t_servo && var_aux_abrir == true) servo = SUBIR;

                    else if(millis() - t_servo_crono >= t_servo)  {
                        servo = PARO;
                        abrir = false;
                        cerrar = false;
                        abierto = true;
                        cerrado = false;
                    }
                }

                else if(cerrar == true && abierto == true){
                    
                    Serial.println("Está abierta y hay que cerrar");
                    if(var_aux_cerrar == false) {
                        t_servo_crono = millis();
                        var_aux_cerrar = true;
                        Serial.println(t_servo_crono);
                    }
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

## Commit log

2021-04-28 LICENSE
    The peer production license is an example of the Copyfair type of license, in which only other commoners, cooperatives and nonprofits can share and re-use the material, but not commercial entities in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
2021-04-28 Create LICENSE
    Actualización de una licencia
2021-05-07 Capturas del render de la PCB eGallinero v2.1
2021-05-11 Distribución de costes
2021-05-27 Código para debug eliminado
2021-06-10 bugs de la puerta solucionados
    [main.cpp]
2021-07-03 Resolución de bugs
2021-07-28 Archivos .stl para imprimir
    [Bobina_1.stl, Bobina_2.stl, Caja.stl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]
2021-10-08 Corrección de dimensiones
    [Caja.stl, Tapa.stl, caja.stl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]
2021-10-08 Eliminación de tapa servo erronea
    [Tapa_servo.stl]
2021-10-09 Añadido soporte para final de carrera
    [soporte_final_de_carrera.stl]
